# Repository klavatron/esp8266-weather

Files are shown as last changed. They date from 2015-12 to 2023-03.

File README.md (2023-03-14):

# esp8266-weather
Esp8266 based weather station for narodmon.ru or other webservices

This is a rough sketch of home weather station based on esp8266-201, esp8866-12f or LoLin NodeMCU module. It gets data from sensors and sends to narodmon.ru.

## NodeMCU board
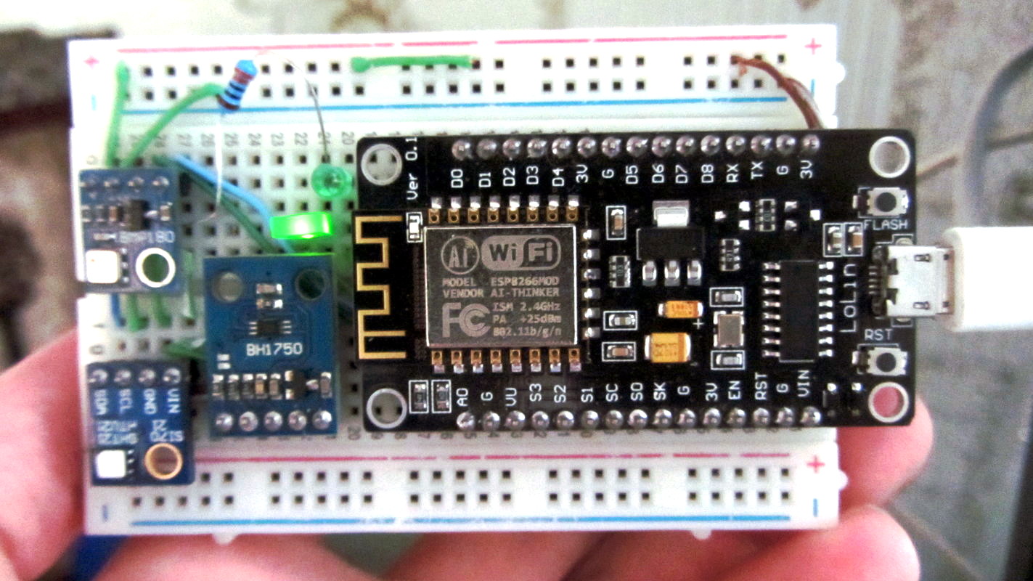
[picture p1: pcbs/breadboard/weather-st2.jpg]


### Parts used:

- Esp8266 esp-12e LoLin NodeMCU
- Breadboard
- bmp180 - barometer and thermometer
- BH1750 - Digital Light Sensor
- HTU21 - Humidity Sensor
- LED + resistor
- wires

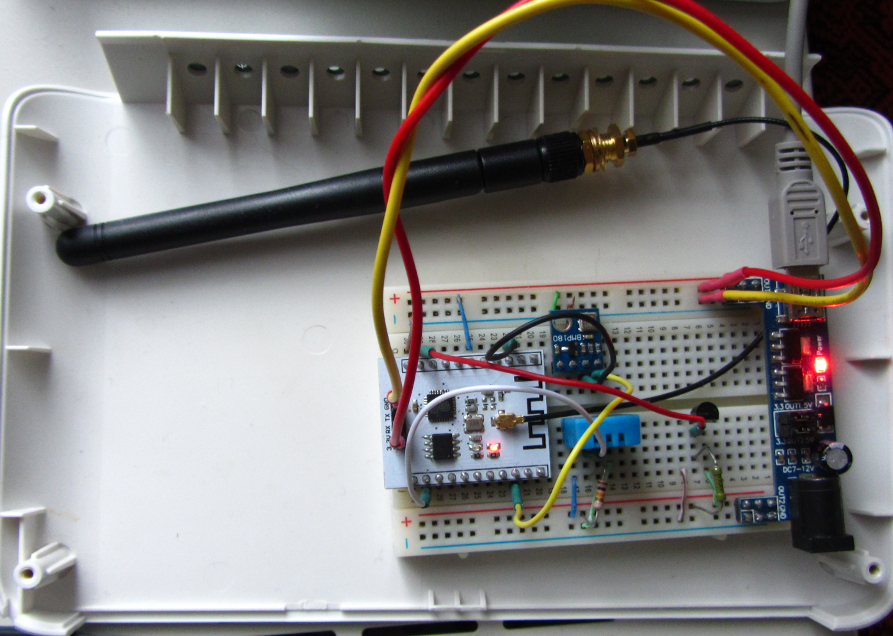
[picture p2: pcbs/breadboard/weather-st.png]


### Parts used:

- Esp8266-201 with antenna
- Breadboard
- bmp180 - barometer and thermometer
- dth11 - humidity and thermometer
- ds18b20 - termometer
- 4.7k and 10k resistors
- 3.3v power supply
- wires

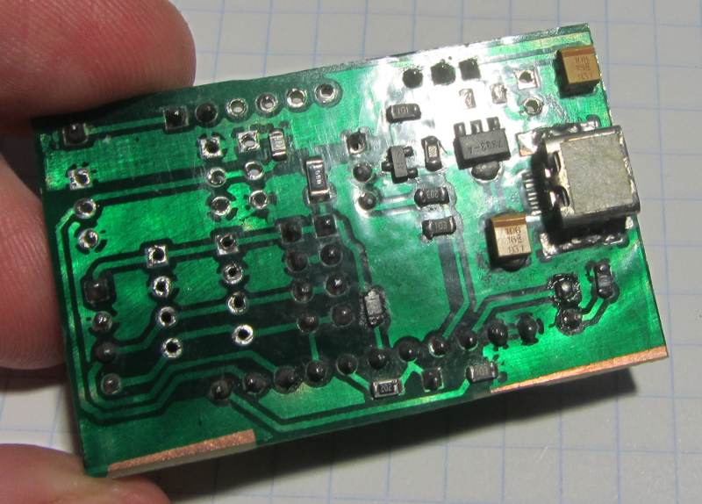
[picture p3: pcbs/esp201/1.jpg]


### Parts used:

- Esp8266-201 with antenna
- bmp180 - barometer and thermometer
- BH1750 - Digital Light Sensor
- HTU21 - Humidity Sensor
- ds18b20 - termometers
- Capacitive soil moisture sensor
- 7333 LDO 3.3v
- resistors, capacitors

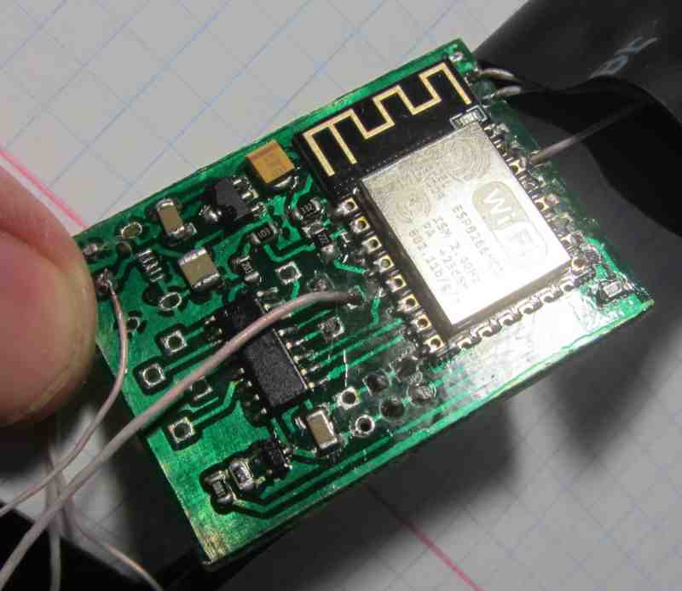
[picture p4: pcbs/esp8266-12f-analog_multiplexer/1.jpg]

  Plants monitor
### Parts used:

- Esp8266-12F
- 7 Capacitive soil moisture sensors
- 7333 LDO 3.3v
- dth11 - humidity and thermometer
- resistors, capacitors

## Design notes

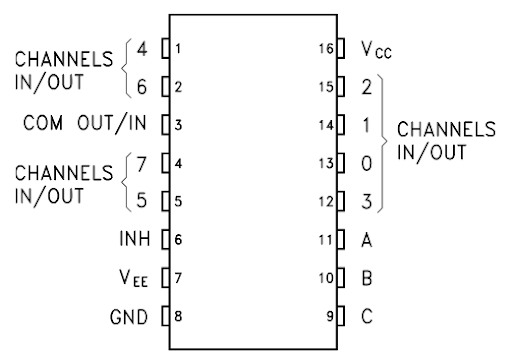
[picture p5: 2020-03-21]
img/hc4051.png

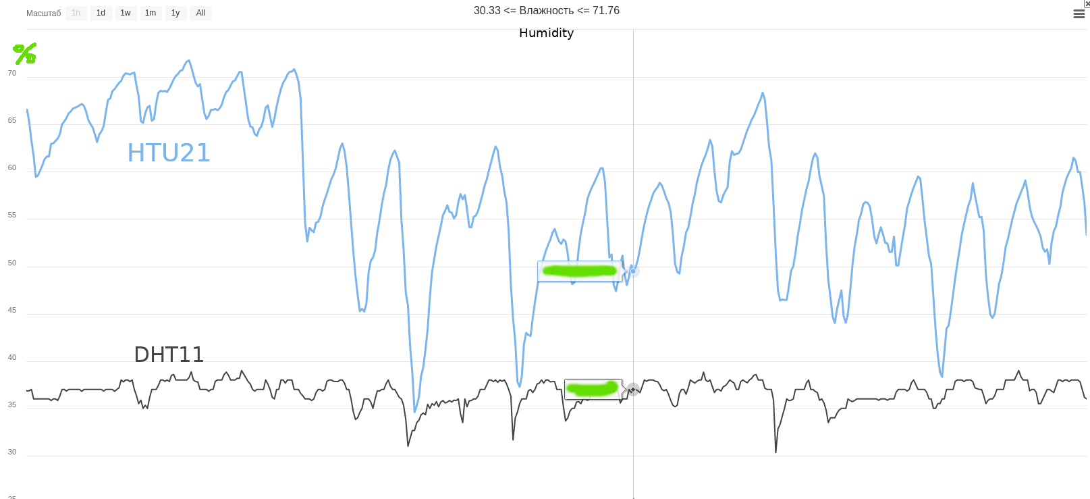
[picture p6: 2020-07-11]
img/HTU21_vs_DHT11.png

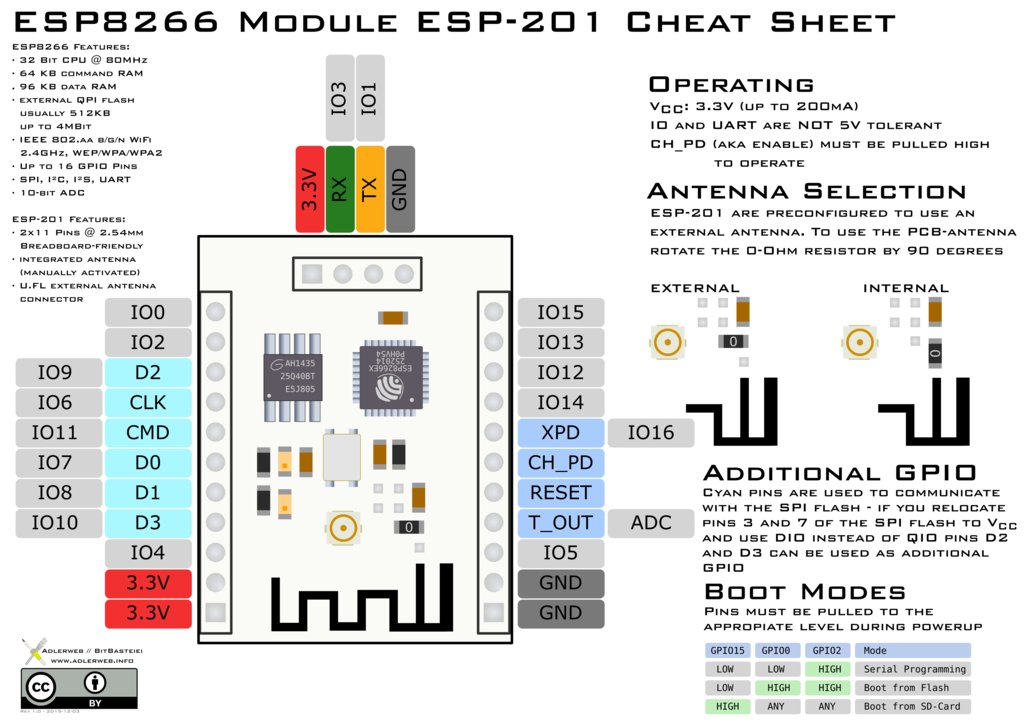
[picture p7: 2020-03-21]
img/esp201.jpg

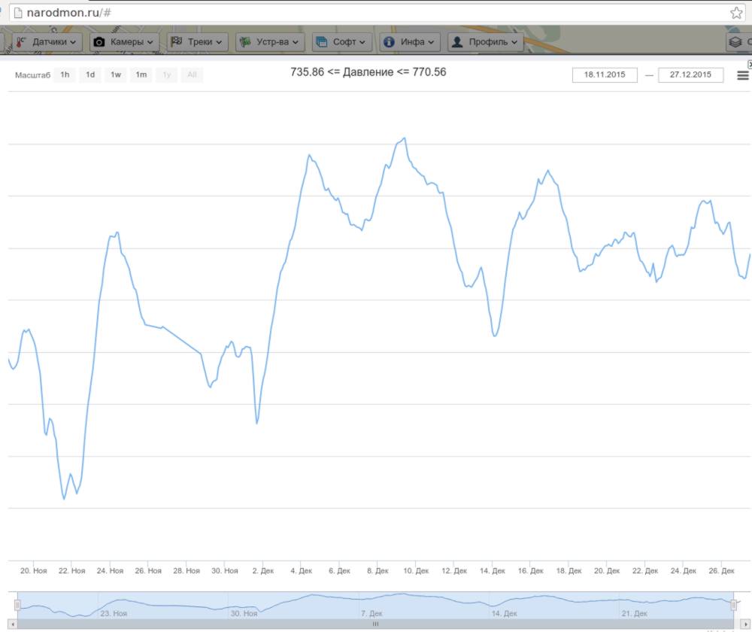
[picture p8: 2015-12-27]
img/narodmon.jpg

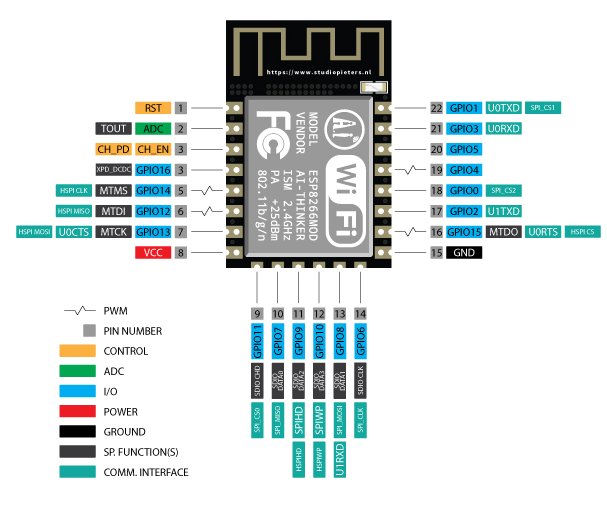
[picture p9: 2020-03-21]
img/ESP8266_12X.jpg

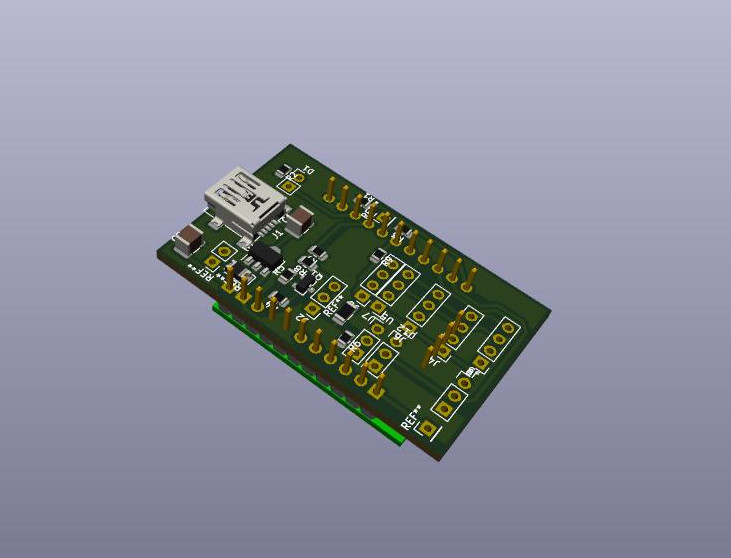
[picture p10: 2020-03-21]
pcbs/esp201/weather1.jpg

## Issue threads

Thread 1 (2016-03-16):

subzero temperature bug

klavatron, 2016-03-16:
subzero values looks like this **=-1.-19**

Closed 2016-03-23.

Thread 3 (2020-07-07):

Прошу добавить SHT1x

TerAnYu, 2020-07-07:
Здравствуйте!
Прошу добавить сенсоры SHT1x.

Библиотека: [SHT1x-ESP](https://github.com/beegee-tokyo/SHT1x-ESP)

689b6985d173bbcf6f26baad8ae21afa4a852181 - мой коммит с изменениями.
Правда есть проблема, не знаю как исправить:
при использовании BMP180 и SHT11, то BMP180 отображает какие-то странные данные, хотя при первом запросе всё корректно
```
runOnce:            Going to check sensors
readSensors:        Going to collect data
readSensors:        BMP180
bmp180 pressure     982.33 hPa
bmp180 temperature  29.70 C
SHT_T:              28.5900001526 C
SHT_H:              61.06 %
runOnce:            Sensors checked

```
далее
```
-->start
WIFI status code: 3
readSensors:        Going to collect data
readSensors:        BMP180
bmp180 pressure     2212.31 hPa
bmp180 temperature  213.00 C
SHT_T:              28.6000003815 C
SHT_H:              60.56 %
-->end
```

klavatron, 2020-07-09:
Хорошо, позже гляну.

klavatron, 2020-07-10:
Возможно, ошибка вызвана тем, что SHTxx это не i2c сенсоры. Есть ли возможность проверить работоспособность с другим i2c сенсором (не bmp180)? Работает ли SHTxx на пинах, отличных от i2c? Если да, то возникает ли описанная проблема, при одновременном подключении bmp180 к пинам с поддержкой i2c, а SHTxx к иным пинам?

TerAnYu, 2020-07-11:
С другим датчиком проверить не смог, есть только DS1631.
Перевёл SHTxx на другие пины - D2 и D3 - всё заработало как положено.
Пробовал с отключенным (но на тех же пинах) SHT11 и подключенным BMP180 - проблема сохраняется.

klavatron, 2020-07-11:
sht.begin() выдаёт ошибку, потому как такой функции, в используемой Вами [библиотеке](https://github.com/beegee-tokyo/SHT1x-ESP/blob/master/SHT1x-ESP.h), нет. В своих примерах, _beegee-tokyo_ сразу опрашивает сенсор.
P.S.
dht и sht - разные сенсоры. SHTxx - 4 контакта, 2-wire serial interface; DHTxx - 3 контакта, one-wire.

**D**HT11 сенсор плохой. Хоть он и реагирует на скачки влажности, но довольно грубый и показания всегда занижены. Использовать крайне не рекомендуется. [Вот пример](https://github.com/klavatron/esp8266-weather/blob/master/img/HTU21_vs_DHT11.png) показывающий разницу в измерениях между HTU21 и DHT11.

TerAnYu, 2020-07-12:
Спасибо за консультацию.

P.S.
Я свои датчики брал уще в 2012 году, выбирал только цифровые, где были низкие показатели погрешности.

klavatron, 2020-07-12:
Перекидал коммиты в [ветку](https://github.com/klavatron/esp8266-weather/tree/feature-sht). Сделал некоторые правки. Если есть возможность проверить работоспособность - будет не плохо. Если будет работать, можно слить в мастер. Не могли бы скинуть скриншот графика SHT-сенсора. Интересно посмотреть диапазоны, в которых он выдаёт показания.

TerAnYu, 2020-07-12:
Работоспособность подтверждаю.
Графики будут завтра, примерно в это же время.

TerAnYu, 2020-07-13:
Данные CSV, что бы наглядно посмотреть, местами есть вспелски.

```
UNIXTIME;DATE;TIME;01;03;BA;BB
1594475220;11.07.2020;20:47:00;987.72;28.4;47.64;28.71
1594475520;11.07.2020;20:52:00;987.64;;46.72;28.66
1594476360;11.07.2020;21:06:00;987.7;;47.7;28.45
1594564200;12.07.2020;21:30:00;985.19;;39.72;31.16
1594564800;12.07.2020;21:40:00;985.26;;39.81;31.11
1594565400;12.07.2020;21:50:00;985.31;;39.68;31.11
1594566000;12.07.2020;22:00:00;985.37;;39.01;31.14
1594566600;12.07.2020;22:10:00;985.24;;38.67;31.08
1594567260;12.07.2020;22:21:00;985.25;;39.21;31.1
1594567860;12.07.2020;22:31:00;985.17;;39.31;31.08
1594568460;12.07.2020;22:41:00;985.34;;40.07;31.04
1594569120;12.07.2020;22:52:00;985.29;29.1;40.8;30.97
1594569720;12.07.2020;23:02:00;985.45;29.4;41.89;30.9
1594570320;12.07.2020;23:12:00;985.28;29;42.2;30.96
1594570920;12.07.2020;23:22:00;985.34;29;42.24;31.09
1594571520;12.07.2020;23:32:00;985.61;29;43.34;31.12
1594572120;12.07.2020;23:42:00;986.21;29.2;43.87;31.15
1594572720;12.07.2020;23:52:00;986.5;29.1;44.53;31.16
1594573320;13.07.2020;00:02:00;986.57;29.3;45.16;31.13
1594573920;13.07.2020;00:12:00;986.71;29.2;44.92;31.12
1594574520;13.07.2020;00:22:00;986.86;29.2;44.99;31.12
1594575120;13.07.2020;00:32:00;986.62;28.9;44.81;31.02
1594575780;13.07.2020;00:43:00;986.5;28.7;45.62;30.9
1594576380;13.07.2020;00:53:00;986.65;27.7;45.71;30.57
1594576980;13.07.2020;01:03:00;986.56;27.9;46.17;30.54
1594577580;13.07.2020;01:13:00;986.51;28.2;46.08;30.33
1594578180;13.07.2020;01:23:00;986.14;28.3;47.14;29.93
1594578780;13.07.2020;01:33:00;986.05;28.4;48.83;29.65
1594579380;13.07.2020;01:43:00;986.37;27.6;49.05;29.36
1594580040;13.07.2020;01:54:00;986.23;27.1;49.48;28.93
1594580640;13.07.2020;02:04:00;986.44;28.1;50.06;28.7
1594581240;13.07.2020;02:14:00;986.46;28.2;50.47;28.6
1594581840;13.07.2020;02:24:00;986.3;28.3;50.9;28.51
1594582440;13.07.2020;02:34:00;986.21;28.3;51.38;28.42
1594583040;13.07.2020;02:44:00;985.98;28.3;52.77;28.35
1594583640;13.07.2020;02:54:00;985.91;27.6;52.12;28.25
1594584240;13.07.2020;03:04:00;985.66;25.9;50.57;27.95
1594584840;13.07.2020;03:14:00;985.43;25.9;50.54;27.72
1594585500;13.07.2020;03:25:00;985.29;25.4;50.87;27.51
1594586100;13.07.2020;03:35:00;985.82;26.2;51.46;27.41
1594586700;13.07.2020;03:45:00;986.01;26.7;51.95;27.48
1594587300;13.07.2020;03:55:00;985.94;26;52.17;27.42
1594587900;13.07.2020;04:05:00;986.15;26.1;52.51;27.35
1594588500;13.07.2020;04:15:00;986.36;27.1;52.32;27.4
1594589100;13.07.2020;04:25:00;986.47;27.3;53.06;27.46
1594589760;13.07.2020;04:36:00;986.48;26.8;53.83;27.48
1594590360;13.07.2020;04:46:00;986.56;27.3;52.62;27.48
1594590960;13.07.2020;04:56:00;986.41;27.4;52.4;27.48
1594591560;13.07.2020;05:06:00;986.56;27.4;52.43;27.49
1594592160;13.07.2020;05:16:00;986.49;27.5;52.15;27.53
1594592760;13.07.2020;05:26:00;986.37;27.4;51.95;27.53
1594593360;13.07.2020;05:36:00;986.38;27.4;51.93;27.53
1594593960;13.07.2020;05:46:00;986.39;27.4;52.59;27.54
1594594620;13.07.2020;05:57:00;986.5;27.5;52.44;27.54
1594595220;13.07.2020;06:07:00;986.34;27.4;52.53;27.53
1594595880;13.07.2020;06:18:00;986.46;27.4;53.42;27.51
1594596480;13.07.2020;06:28:00;986.4;27.3;52.62;27.48
1594597080;13.07.2020;06:38:00;986.49;27.3;52.2;27.46
1594597680;13.07.2020;06:48:00;986.57;27.3;52.24;27.47
1594598280;13.07.2020;06:58:00;986.55;27.3;52.55;27.46
1594598880;13.07.2020;07:08:00;986.5;27.2;52.49;27.46
1594599480;13.07.2020;07:18:00;986.56;27.2;52.74;27.44
1594600080;13.07.2020;07:28:00;986.63;27.2;52.71;27.4
1594600680;13.07.2020;07:38:00;986.69;27.1;53.31;27.39
1594601280;13.07.2020;07:48:00;986.82;27.1;53.08;27.35
1594601880;13.07.2020;07:58:00;987;27.1;53.2;27.31
1594602480;13.07.2020;08:08:00;987.11;27.2;53.42;27.3
1594603080;13.07.2020;08:18:00;987.08;27.1;53.29;27.29
1594603740;13.07.2020;08:29:00;987.16;27.2;53.73;27.26
1594604340;13.07.2020;08:39:00;987.14;27.1;53.6;27.26
1594604940;13.07.2020;08:49:00;987.13;27.1;53.57;27.26
1594605540;13.07.2020;08:59:00;987.12;27.1;53.41;27.24
1594606140;13.07.2020;09:09:00;987.08;27;53.28;27.23
1594606740;13.07.2020;09:19:00;987.13;27.1;53.22;27.25
1594607340;13.07.2020;09:29:00;987.05;27.1;53.12;27.22
1594607940;13.07.2020;09:39:00;987.2;27.1;53.09;27.24
1594608600;13.07.2020;09:50:00;987.18;27.2;53.09;27.24
1594609200;13.07.2020;10:00:00;987.29;27.1;53.15;27.21
1594609800;13.07.2020;10:10:00;987.41;27.1;53.03;27.21
1594610400;13.07.2020;10:20:00;987.47;27.1;52.96;27.18
1594611000;13.07.2020;10:30:00;987.71;27.1;52.77;27.16
1594611600;13.07.2020;10:40:00;987.81;27.1;52.73;27.15
1594612200;13.07.2020;10:50:00;987.92;27;52.7;27.14
1594612800;13.07.2020;11:00:00;987.92;27;52.51;27.14
1594613400;13.07.2020;11:10:00;988;27.1;52.64;27.15
1594614060;13.07.2020;11:21:00;988;27.2;52.58;27.17
1594614660;13.07.2020;11:31:00;988.05;27.1;52.58;27.18
1594615260;13.07.2020;11:41:00;988.13;27.2;52.49;27.2
1594615860;13.07.2020;11:51:00;988.1;27.2;52.52;27.2
1594616460;13.07.2020;12:01:00;988.02;27.3;52.46;27.22
1594617060;13.07.2020;12:11:00;988;27.3;52.46;27.25
1594617600;13.07.2020;12:20:00;988.1;27.4;52.91;27.28
1594618260;13.07.2020;12:31:00;988.19;27.4;52.63;27.32
1594618800;13.07.2020;12:40:00;988.12;27.4;52.34;27.32
1594619460;13.07.2020;12:51:00;988.09;27.4;52.57;27.32
1594620060;13.07.2020;13:01:00;988.12;27.4;53.05;27.34
1594620600;13.07.2020;13:10:00;988.29;27.4;53.4;27.35
1594621260;13.07.2020;13:21:00;988.24;27.4;53.75;27.34
1594621860;13.07.2020;13:31:00;988.17;27.4;54.47;27.34
1594622460;13.07.2020;13:41:00;988.16;27.4;55.92;27.34
1594623060;13.07.2020;13:51:00;988.15;27.5;57.59;27.38
1594623660;13.07.2020;14:01:00;988.15;27.6;58.54;27.43
1594624260;13.07.2020;14:11:00;988.03;27.7;58.17;27.48
1594624860;13.07.2020;14:21:00;988.07;27.7;57.83;27.49
1594625520;13.07.2020;14:32:00;988.17;27.7;57.61;27.51
1594626120;13.07.2020;14:42:00;988.11;27.6;56.77;27.53
1594626720;13.07.2020;14:52:00;988.05;27.7;56.49;27.53
1594627320;13.07.2020;15:02:00;988;27.7;56.11;27.56
1594627920;13.07.2020;15:12:00;988.08;27.7;55.55;27.59
1594628520;13.07.2020;15:22:00;988.07;27.7;54.67;27.6
1594629120;13.07.2020;15:32:00;988.1;27.7;54.8;27.61
1594629720;13.07.2020;15:42:00;988.14;27.8;55.62;27.62
1594630320;13.07.2020;15:52:00;988.2;27.8;55.72;27.63
1594630920;13.07.2020;16:02:00;988.27;27.8;55.81;27.67
1594631520;13.07.2020;16:12:00;988.38;27.8;55.78;27.66

```

klavatron, 2020-07-13:
В первых строках лога у bmp180 отсутствует показания температуры? Странно. Когда зависла, вывод серийного порта куда-то писался? Собрано на макетке или запаяно? Спящий режим не используется? Питание не проседает на датчиках? У меня раньше были проблемы с каким-то датчиком, он наглухо вешался. По этой причине стал запитывать сенсоры через мосфет, включаемый на время опроса сенсоров. Стало работать стабильнее.

TerAnYu, 2020-07-14:
bmp180 я позже включил, решил для сравнения добавить. К сожалению вывод никуда не писался.
Сегодня опять завис.
Датчики припаяны, правда на проводах...
Спящий режим вроде не используется.
Завтра попробую на WeMos переделать.
Питание через блок питания с литиевым аккумулятором, якобы бесперебойник. Питание не проверял, думаю что 1А должно хватать :)
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

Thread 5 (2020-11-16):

Звисание устройства

TerAnYu, 2020-11-16:
Здравствуйте!
Получилось, наконец-таки, собрать дамп, когда данные перестают передаваться:
```
-->start
WIFI status code: 3
readSensors:        Going to collect data
readSensors:        BMP180
bmp180 pressure     1000.42 hPa
bmp180 temperature  27.00 C
SHT_T:              30.0400009155 C
SHT_H:              32.84 %

Compiled string: ID=MACADDRESSS000000&MACADDRESSS00000001=1000.42&MACADDRESSS00000003=27.00&MACADDRESSS000000BA=32.84&MACADDRESSS000000BB=30.04
=============== send msg start ==============
-------------- host unreachable -------------
reboot in 10 sec
---------------------------------------------

```
После этого устройство более не отвечает, пока не перезапустишь по питанию.

klavatron, 2020-11-16:
Приветствую! RST через резистор (например 3Ком) подключен на GPIO16?

TerAnYu, 2020-11-16:
Спасибо!
Был не в курсе такого нюанса и в документации тоже не написано.
В моём случае помогла только перемычка (между RST и D0).

klavatron, 2020-11-16:
Надо добавить в описание этот нюанс. Дело в том, что при использовании "спящего режима", а он там использовался, чтобы ESP8862 нормально проснулась, надо ногу RST подключать к WAKE (GPIO16 она же D0). Вместо перемычки, всё же лучше подобрать резистор.

Closed 2020-11-16.

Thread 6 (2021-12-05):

Отрицательные температуры отображаются коряво ds18b20

b8hri11, 2021-12-05:
Отрицательные температуры отображаются коряво
2021-12-05 10:06:29  *.*.*.*  POST  28FF2D94A2150478=--2.0-94 not a number  ID=*&28FF2D94A2150478=--2.0-94

klavatron, 2021-12-06:
хм... действительно

klavatron, 2021-12-06:
Поправил

Closed 2021-12-06.

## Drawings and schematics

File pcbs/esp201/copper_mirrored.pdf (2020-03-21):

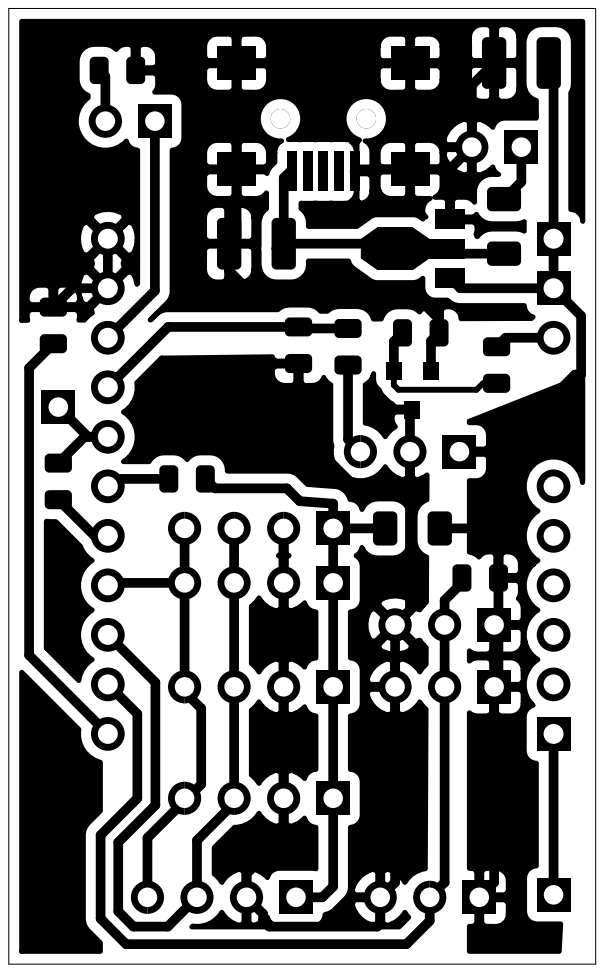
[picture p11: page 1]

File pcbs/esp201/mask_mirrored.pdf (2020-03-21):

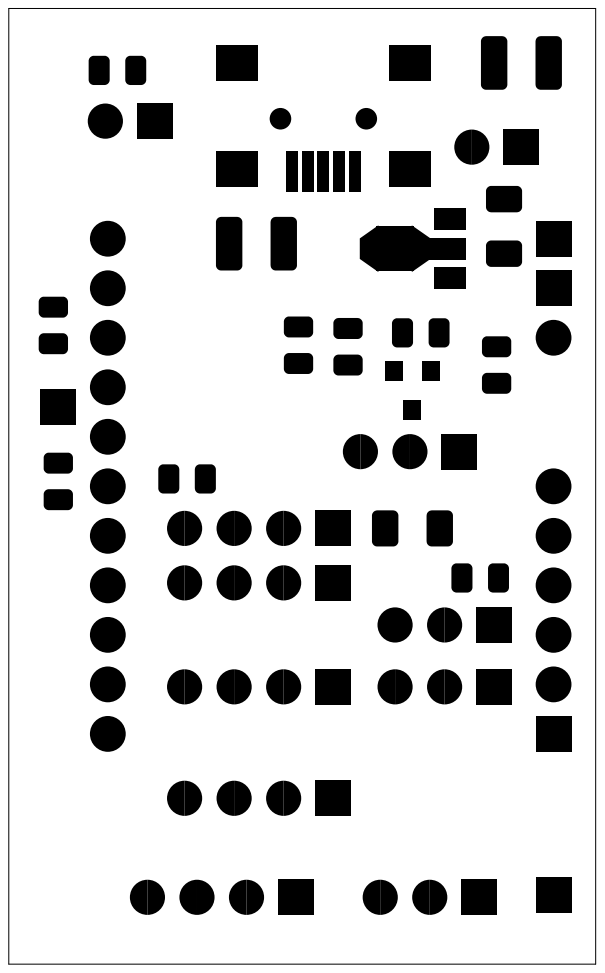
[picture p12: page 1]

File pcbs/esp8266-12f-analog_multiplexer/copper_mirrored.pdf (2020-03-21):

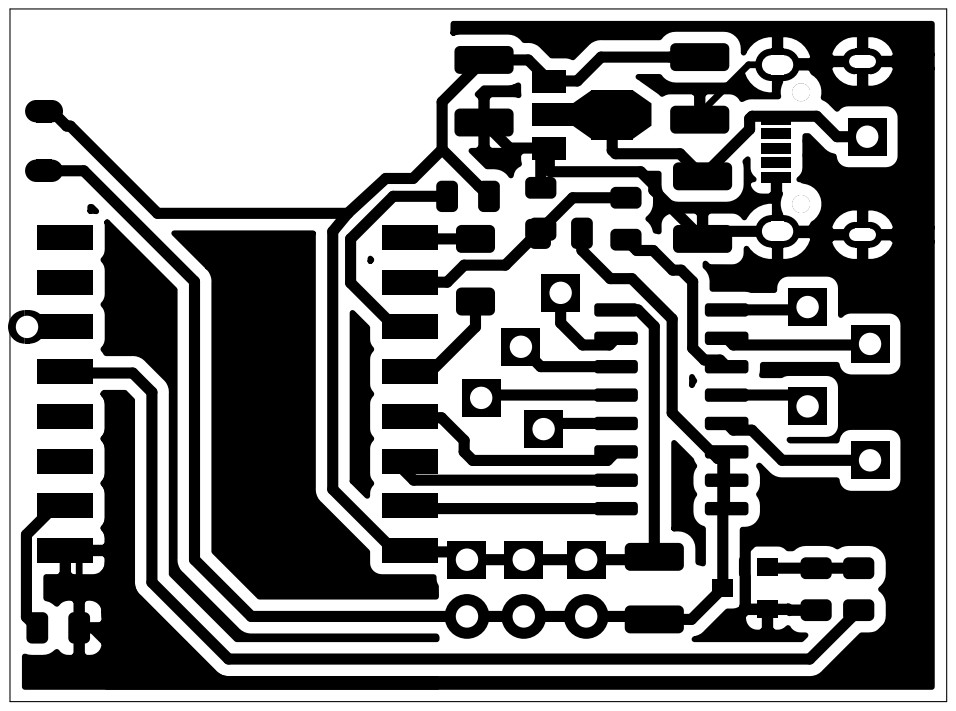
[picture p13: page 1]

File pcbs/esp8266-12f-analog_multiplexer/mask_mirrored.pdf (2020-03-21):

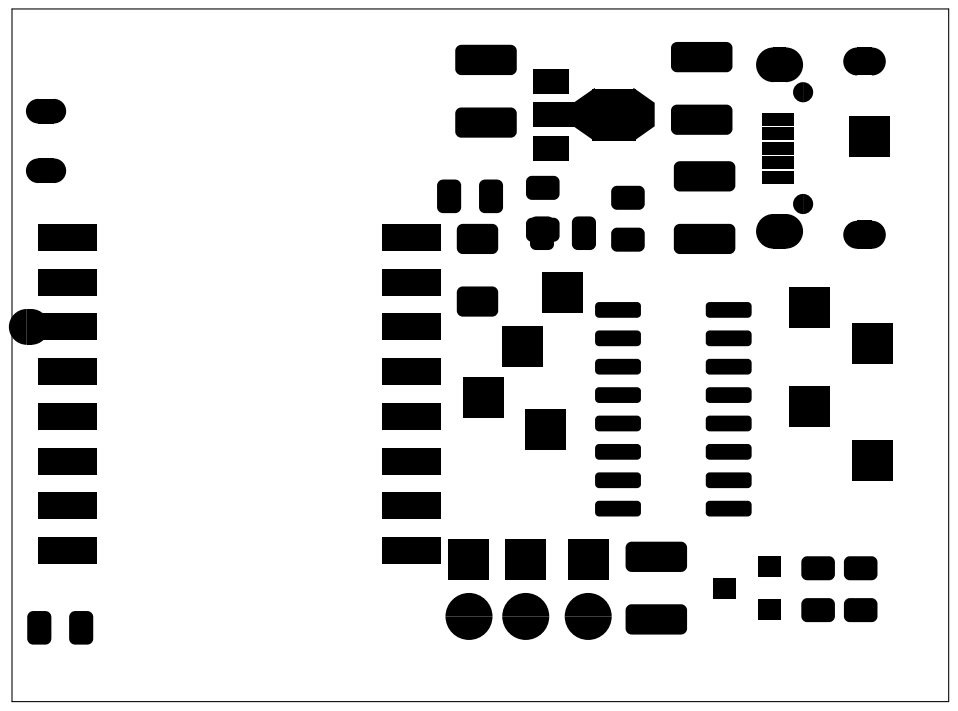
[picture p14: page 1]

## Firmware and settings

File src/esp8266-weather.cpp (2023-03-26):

/*
*  This sketch sends data via HTTP POST requests to narodmon.ru service.
*  Copyright <klavatron> 2015-2023
*
*  ***DRAFT***
*           ESP8266 BoardVersion 2.6.3 https://github.com/esp8266/Arduino
*
*  List of supported sensors:
*                         Adafruit Unified Sensor Driver 1.1.4 https://github.com/adafruit/Adafruit_Sensor
*           bmp180  i2c   Adafruit BMP085 Unified 1.1.0 https://github.com/adafruit/Adafruit_BMP085_Unified
*                         Adafruit GFX Library 1.1.8 https://github.com/adafruit/Adafruit-GFX-Library
*           OLED    i2c   2.0.1 Adafruit SSD1306 oled driver library for monochrome 128x64 and 128x32 
*                               displays https://github.com/adafruit/Adafruit_SSD1306
*           BH1750  i2c   1.1.4 Christopher Laws https://github.com/claws/BH1750.git
*           !HTU21  i2c   1.0.2 Adafruit HTU21DF Library with modified begin() 
*             -->               function https://github.com/klavatron/Adafruit_HTU21DF_Library.git
*           *(dont use it) CCS811  i2c   1.0.1 DFRobot_CCS811 https://github.com/DFRobot/DFRobot_CCS811
*           dth11         Adafruit DHT sensor library 1.3.8 https://github.com/adafruit/DHT-sensor-library
*           SHT1x   2wire       beegee-tokyo  https://github.com/beegee-tokyo/SHT1x-ESP
*           ds18b20 onewire DallasTemperature 3.7.6 https://github.com/milesburton/Arduino-Temperature-Control-Library.git
*           *Analog        You need to use voltage divider to keep analog voltage in range 0..1v (LoLin NodeMCU already has it)
*           *Multiplexer   8-ch analog Multiplexer hc4051. You need to use voltage divider to keep analog 
*                               voltage in range 0..1v (LoLin NodeMCU already has it). May be usefull for polling 7-8 Capacitive
*                               Soil Moisture sensors from one ESP device
*                           
*           Remove .example extention for wifi.cfg.h.example file
*           edit:
*             ssid = "YOUR-WIFI" - name of existing wifi AP
*             password = "YOUR-PASSWORD" - password of wifi AP
*
*           If you want to send data to narodmon.ru remove .example extention for narodmon.cfg.h.example file
*           edit:
*             narodmonDevId = "ABCDEF012345"- hw address of device
*             host = "185.245.187.136" - ip of narodmon.ru
*
*           Edit defines.h to chose your sensors. Edit pins.h to assign chosen sensord to pins of ESP8266.
*           You can't use all sensors in one device because there is not enough available pins for them.
*
* If you don't use oled screen or debug logging, switch USE_SLEEP_MODE to 1 for powersaving.
*/
#include "Arduino.h"
#include "defines.h"

void setup()
{
  #if DEBUG == 1
    Serial.begin(SERIAL_SPEED);
    Serial.print("\r\n\nSketch: ");
    Serial.println(__FILE__);
    Serial.println("Compiled: " __DATE__ ", " __TIME__);
    Serial.println("\n=================== CONFIG ==================");
  #endif //DEBUG

  #if MOSFETSENSORS == 1 //if using mosfet for powering sensors
    pinMode(POWERPIN, OUTPUT);
    turnSensorsON();
  #endif //MOSFETSENSORS

  delay(100);

  #if MUX_EXIST == 1
    #if DEBUG == 1
      Serial.println("Multiplexer         init");
    #endif //DEBUG

    pinMode(mux_data_line, INPUT);

    for (int i = 0; i < 3; i++)
    {
      pinMode(mux_control_pins[i], OUTPUT);
    }
  #endif // MUX_EXIST

  #if WEBCONFIG == 1
    // check if webconfig button pressed
    #if MUX_EXIST == 1
      muxSwitchTo(MUX_BUTTON_PIN);
      if (analogRead(A0) > 300)
      {
        isConfigMode = true;
      }
    #else // MUX_EXIST
      pinMode(BUTTON_PIN, INPUT_PULLUP);
      if (!digitalRead(BUTTON_PIN))
      {
        isConfigMode = true;
      }
    #endif // MUX_EXIST
    // ENDOF check if webconfig button pressed

    if (isConfigMode) //if mux MUX_BUTTON_PIN is high -> configboot
    {
      #if DEBUG == 1
        Serial.println("Entering configuration mode");                                                                        
      #endif // DEBUG

      WiFi.mode(WIFI_STA);
      WiFi.begin(ssid, password);

      // Wait for connection
      while ((WiFi.status() != WL_CONNECTED) && sta_connection_attempts)
      {
        delay(1000);

        #if DEBUG == 1
          Serial.print(".");
        #endif // DEBUG

        sta_connection_attempts--;
      }

      //if cant connect in STA mode, create AP
      if (sta_connection_attempts <= 0)
      {
        #if DEBUG == 1
          Serial.println("AP mode");
        #endif //DEBUG

        WiFi.mode(WIFI_AP);
        WiFi.softAP(ap_ssid, ap_password);
        IPAddress myIP = WiFi.softAPIP();

        #if DEBUG == 1
          Serial.print("AP IP address: ");
          Serial.println(myIP);
        #endif // DEBUG
      }
      else
      {
        #if DEBUG == 1
          Serial.println("");
          Serial.print("Connected to ");
          Serial.println(ssid);
          Serial.print("IP address: ");
          Serial.println(WiFi.localIP());
        #endif // DEBUG
      }

      if (!MDNS.begin(mdnshost))
      {
        #if DEBUG == 1
          Serial.println("Error setting up MDNS responder!");
        #endif // DEBUG

        while (1)
        {
          delay(1000);
        }
      }

      #if DEBUG == 1
        Serial.println("mDNS responder started");
        Serial.println("In configuration mode");
      #endif // DEBUG

      httpUpdater.setup(&httpServer, update_path, update_username, update_password);
      httpServer.begin();

      MDNS.addService("http", "tcp", 80);

      #if DEBUG == 1
        Serial.print("WEB UPDATER on ");
        Serial.println(WiFi.localIP());
        Serial.printf("HTTPUpdateServer ready! Open http://%s.local%s in your browser and login with username '%s' and password '%s'\n", mdnshost, update_path, update_username, update_password);
      #endif // DEBUG

      while (1) // loop()
      {
        httpServer.handleClient();
        MDNS.update();
      }
    }
    delay(100);
  #endif // WEBCONFIG

  #if USE_SLEEP_MODE == 0 // if not using deep sleep
    lastUpdateMillis = millis();
  #endif // USE_SLEEP_MODE

  #if NARODMON == 1
    lastSendMillis = millis();
  #endif //NARODMON

  //if I2C used
  #if (OLED == 1) || (BMP_EXIST == 1) || (BH1750_EXIST == 1) || (HTU21_EXIST == 1) || (CCS811_EXIST == 1)
    Wire.begin(WIRESDA, WIRESCL);
    delay(100);
  #endif

  #if USELED == 1
    pinMode(INDICATORLED, OUTPUT);
    digitalWrite(INDICATORLED, LOW);
  #endif //USELED

  #if OLED == 1
    if (!display.begin(SSD1306_SWITCHCAPVCC, 0x3C))
    { // bug. always TRUE // Address 0x3D for 128x64, 0x3C for 128x32 and some 128x64 oled displays
      #if DEBUG == 1
        Serial.println("OLED initialization error");
      #endif
      oled_error = true;
    }
    else
    {
      #if DEBUG == 1
        Serial.println("OLED initialization Ok");
      #endif
    }

    if (!oled_error)
    {
      delay(300);
      display.clearDisplay();
      display.setTextSize(1);
      display.setTextColor(WHITE);
      display.setCursor(0, 0);
      display.println("ESP weather");
      display.display();
      delay(500);
    }
  #endif //OLED

  #if WIFI == 1
    #if OLED == 1
      if (!oled_error)
      {
        display.clearDisplay();
        display.setCursor(0, 0);
        display.println("Connecting to: ");
        display.setCursor(0, 16);
        display.println(ssid);
        display.display();
      }
    #endif //OLED

    #if DEBUG == 1
      #if NARODMON == 1
        Serial.print("Narodmon IP:        ");
        Serial.println(host);
      #endif //NARODMON

      Serial.print("Connecting to:      ");
      Serial.print(ssid);
      Serial.print(" ");
    #endif //DEBUG

    //WiFi.forceSleepWake();
    WiFi.mode(WIFI_STA);
    delay(100);

    #if OLED == 1
      if (!oled_error)
      {
        display.setCursor(0, 32);
      }
    #endif //OLED

    if (WiFi.SSID())
    {
      #if DEBUG == 1
        Serial.print("x");
      #endif //DEBUG
      WiFi.begin();
    }
    else
    {
      #if DEBUG == 1
        Serial.print("X");
      #endif //DEBUG
      WiFi.begin(ssid, password);
    }
    delay(100);
    int attempts = 0;

    while (WiFi.status() != WL_CONNECTED)
    {
      attempts++;
      if (attempts == 10)
      {
        WiFi.begin(ssid, password);
      }
      if (attempts > 20)
      {
        wifi_error = true;
        break;
      }
      delay(1000);

      #if DEBUG == 1
        Serial.print(".");
      #endif //DEBUG

      #if OLED == 1
        if (!oled_error)
        {
          display.print(".");
          display.display();
        }
      #endif //OLED

      #if USELED == 1
        ledBlink(50, 1);
      #endif //USELED
    }

    #if USELED == 1
      ledBlink(100, 2);
    #endif //USELED

    #if DEBUG == 1
      if (!wifi_error)
      {
        Serial.println(" OK");
        Serial.print("IP address:         ");
        Serial.println(WiFi.localIP());
      }
      else
      {
        Serial.println("WiFi error");
      }
    #endif //DEBUG

    #if OLED == 1
      if (!oled_error)
      {
        if (!wifi_error)
        {
          delay(50);
          display.println("OK");
          display.display();
          display.setCursor(0, 48);
          display.print("IP:");
          display.println(WiFi.localIP());
          display.display();
        }
        else
        {
          delay(50);
          display.println("WiFi Err");
          display.display();
        }
      }
    #endif //OLED

    delay(500);
  #endif //WIFI

  #if DALLAS_EXIST == 1
    delay(50);
    dallas_sensors.begin();
    countOfDallasTerm = dallas_sensors.getDeviceCount();

    if (countOfDallasTerm <= 0)
      dallas_error = true;

    #if DEBUG == 1
      Serial.print("Locating dallas devices...\t");
      (countOfDallasTerm > 0) ? Serial.print(" OK\n") : Serial.print(" FAIL\n");
      Serial.print("Found ");
      Serial.print(countOfDallasTerm, DEC);
      Serial.println(" devices.");
    #endif //DEBUG

    if (!dallas_error)
    {
      for (int i = 0; i < countOfDallasTerm; i++)
      {
        // Search the wire for address
        if (dallas_sensors.getAddress(tempDeviceAddress, i))
        {
          #if DEBUG == 1
            Serial.print("Dallas thermometer: ");
            printAddress(tempDeviceAddress);
            Serial.println();
          #endif //DEBUG
          // set the resolution to 9 bit (Each Dallas/Maxim device is capable of several different resolutions)
          dallas_sensors.setResolution(tempDeviceAddress, TEMPERATURE_PRECISION);
        }
        else
        {
          #if DEBUG == 1
            Serial.print("Found ghost device at ");
            Serial.print(i, DEC);
            Serial.print(" but could not detect address. Check power and cabling");
          #endif //DEBUG
        }
      }
    }
  #endif //DALLAS_EXIST

  #if BMP_EXIST == 1
    delay(50);
    if (!presureSensor.begin())
    {
      #if DEBUG == 1
        Serial.println("BMP                 fail");
      #endif //DEBUG
      bmp_error = true;
    }
    else
    {
      #if DEBUG == 1
        Serial.println("BMP                 init");
      #endif //DEBUG
      getBMPsensor();
    }
  #endif //BMP_EXIST

  #if BH1750_EXIST == 1
    delay(50);

    if (lightMeter.begin(BH1750::CONTINUOUS_HIGH_RES_MODE_2))
    {
      #if DEBUG == 1
        Serial.println("BH1750              init");
      #endif //DEBUG
    }
    else
    {
      bh1750_error = true;
      #if DEBUG == 1
        Serial.println("BH1750              fail");
      #endif //DEBUG
    }
  #endif //BH1750_EXIST

  #if ANALOG_SENSOR == 1
    delay(50);
    pinMode(ANALOG_PIN, INPUT);

    #if DEBUG == 1
      Serial.println("Analog pin          init");
    #endif //DEBUG

  #endif //ANALOG_SENSOR

  #if DHT_EXIST == 1
    #if DEBUG == 1
      Serial.println("DHT                 init");
    #endif //DEBUG
    dht.begin();
    delay(100);
  #endif //DHT_EXIST

  #if SHT_EXIST == 1
    #if DEBUG == 1
      Serial.println("SHT                 init");
    #endif //DEBUG
  #endif //SHT_EXIST

  #if HTU21_EXIST == 1
    delay(50);

    if (!htu21.begin())
    {
      #if DEBUG == 1
        Serial.println("Error. Couldn't find HTU21!");
      #endif //DEBUG
      htu21_error = true;
    }
    else
    {
      #if DEBUG == 1
        Serial.println("HTU21               init");
      #endif //DEBUG
    }
  #endif //HTU21_EXIST

  #if CCS811_EXIST == 1 // <-------- i2c
    delay(50);

    if(ccs.begin() != 0){
      #if DEBUG == 1
        Serial.println("Failed to start sensor! Please check your wiring.");
      #endif //DEBUG
      ccs811_error = true;
    }
    else{
      #if DEBUG == 1
        Serial.println("CCS811              init");
      #endif //DEBUG
    }
  #endif //CCS811_EXIST


  #if DEBUG == 1
    Serial.println("=============== END OF CONFIG ===============");
    Serial.println("");
  #endif
  delay(100);

  runOnce();
} // setup()

void loop()
{
  #if USE_SLEEP_MODE != 1
    currentUpdateMillis = millis();
    if (currentUpdateMillis - lastUpdateMillis >= updateInterval)
    {
      lastUpdateMillis = currentUpdateMillis;
      update_flag = true;
    }

    // if it's time to update - read sensors, send data
    if (update_flag == true)
    {
      #if DEBUG == 1
        Serial.println("\r\n\n-->start");
        Serial.print("WIFI status code: ");
        Serial.println(WiFi.status());
      #endif //DEBUG

      readSensors();

      #if USELED == 1
        ledBlink(200, 3);
      #endif //USELED

      #if OLED == 1
        displayDraw();
      #endif //OLED

      #if NARODMON == 1
        currentSendMillis = millis();

        if (currentSendMillis - lastSendMillis >= sendPeriod)
        {
          lastSendMillis = currentSendMillis;
          send_allow_flag = true;
        }
        else
        {
          #if DEBUG == 1
            Serial.print("Next delivery in ");
            Serial.print(round((sendPeriod - (currentSendMillis - lastSendMillis)) / 1000));
            Serial.println(" seconds");
          #endif //DEBUG
        }

        // if it's time to send post message - send message
        if (send_allow_flag == true)
        {
          if (!wifi_error)
          {
            send_message(POST_string);
          }
          else
          {
            #if DEBUG == 1
              Serial.println("Cannt POST to server. WiFi error");
            #endif
          }
        }
      #endif //narodmon

      update_flag = false;
      #if DEBUG == 1
        Serial.println("-->end");
      #endif //DEBUG
    }    //if(update_flag == true)
  #endif //!USE_SLEEP_MODE
} // loop()

String floatToString(float src, char decimal_point)
{
  String data = "";
  if (src < 0) //check for minus sign
  {
    data = "-";
  }
  int a, b, c;
  a = (int)abs(round(src * 100));
  b = (int)floor(a / 100);
  c = (int)floor(a % 100);
  data += String(b);
  data += String(decimal_point);

  if (c >= 10)
  {
    data += String(c);
  }
  else
  {
    data += "0";
    data += String(c);
  }
  return data;
} // floatToString()

#if USE_SLEEP_MODE == 1
  void goto_sleep()
  {
    #if DEBUG == 1
      Serial.println("Do nothing for 10 seconds"); // This makes it easier to re-flash the chip later.
    #endif                                         //DEBUG
      delay(10000);

    #if DEBUG == 1
      Serial.print("Going to sleep for ");
      Serial.print(round(SLEEPING_TIME / 60e6));
      Serial.println(" min");
    #endif //DEBUG

    #if MOSFETSENSORS == 1
      turnSensorsOFF();
    #endif //MOSFETSENSORS

    #if USELED == 1
      ledBlink(400, 3);
    #endif
      ESP.deepSleep(SLEEPING_TIME, WAKE_RF_DEFAULT); //20 sec

    #if DEBUG == 1
      Serial.println("Why im not sleeping?");
    #endif //DEBUG
  } // goto_sleep()
#endif //USE_SLEEP_MODE

#if USELED == 1
  void ledBlink(int duration, int count)
  {
    for (int i = 0; i < count; i++)
    {
      digitalWrite(INDICATORLED, HIGH); // turn the LED on
      delay(duration);
      digitalWrite(INDICATORLED, LOW); // turn the LED off
      delay(duration);
    }
  } // ledBlink()
#endif //USELED

#if NARODMON == 1
void send_message(String data)
{
  #if DEBUG == 1
    Serial.println("=============== send msg start ==============");
  #endif //DEBUG

  #if WIFI == 1
    if (WiFi.status() == WL_CONNECTED)
    {
      WiFiClient client;
      if (!client.connect(host, httpPort))
      {
        #if DEBUG == 1
          Serial.println("-------------- host unreachable -------------");
          Serial.println("               reboot in 10 sec              ");
          Serial.println("---------------------------------------------");
        #endif //DEBUG
        #if USELED == 1
          ledBlink(50, 5);
        #endif
          ESP.deepSleep(10000, WAKE_RF_DEFAULT); //sleep 10 sec
      }

      #if DEBUG == 1
        Serial.println("WIFI:               Connected\n");
      #endif //DEBUG

      client.print(String("POST http://narodmon.ru/post.php HTTP/1.0\r\nHost: narodmon.ru\r\nContent-Type: application/x-www-form-urlencoded\r\n"));
      client.print(String("Content-Length: " + String(data.length()) + "\r\n\r\n" + data + "\r\n\r\n"));

      #if DEBUG == 1
        Serial.println(String("POST http://narodmon.ru/post.php HTTP/1.0\r\nHost: narodmon.ru\r\nContent-Type: application/x-www-form-urlencoded\r\n"));
        Serial.println(String("Content-Length: " + String(data.length()) + "\r\n\r\n" + data + "\r\n\r\n"));
        Serial.println("Server reply begin =====>");
      #endif //DEBUG

      delay(50);
      while (client.available())
      {
        String line = client.readStringUntil('\r');

        #if DEBUG == 1
          Serial.print(line);
          Serial.print(String(line.length()));
        #endif //DEBUG

        #if OLED == 1
          if (!oled_error)
          {
            display.clearDisplay();
            display.setCursor(0, 0);
            display.println(line.substring(0, 20));
            display.display();
          }
        #endif //OLED

        delay(100);
      }
      #if DEBUG == 1
        Serial.println("Server reply end <===== ");
        Serial.println("closing connection");
      #endif //DEBUG

      client.stop();
      #if DEBUG == 1
        Serial.println("wait 3 sec...");
      #endif //DEBUG
      delay(3000);
    }
    else
    {
      #if DEBUG == 1
        Serial.println("------------- wifi not connected ------------");
        Serial.println("               reboot in 10 sec              ");
        Serial.println("---------------------------------------------");
      #endif // DEBUG
      #if USELED == 1
        ledBlink(100, 5);
      #endif
      ESP.deepSleep(10000, WAKE_RF_DEFAULT); //sleep 10 sec

      #if DEBUG == 1
        Serial.println("Why im not sleeping?");
      #endif //DEBUG
    }
  #endif //WIFI
  send_allow_flag = false;

  #if DEBUG == 1
    Serial.println("=============== send msg end ==============");
  #endif //DEBUG
} // send_message()
#endif //NARODMON
// ###########################

void runOnce()
{
  #if DEBUG == 1
    Serial.println("runOnce:            Going to check sensors");
  #endif //DEBUG

  readSensors();

  #if DEBUG == 1
    Serial.println("runOnce:            Sensors checked");
  #endif //DEBUG

  #if OLED == 1
    displayDraw();
  #endif //oled

  #if USE_SLEEP_MODE == 1
    checkResetInfo(); // send request to server if waked after sleep
  #endif // USE_SLEEP_MODE

  #if USELED == 1
    ledBlink(100, 3);
  #endif // USELED

  #if NARODMON == 1
    POST_string = "";
  #endif //NARODMON

  #if USE_SLEEP_MODE == 1
    goto_sleep();
  #endif //USE_SLEEP_MODE
} // runOnce()
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

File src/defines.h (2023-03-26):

#pragma once
#include "Arduino.h"

/*
 * #define SOME_FEATURE 0 
 * bool some_feature_error = false;
 * 
 * #if SOME_FEATURE == 1
 *    #include ...
 *    float ...
 *    ....
 * #endif //SOME_FEATURE
 */

#define DEBUG 1          // serial logging enabled
#define USELED 0         // led indicator enabled
#define USE_SLEEP_MODE 1 // powersaving sleep mode enabled
#define MOSFETSENSORS 0  // using mosfet to powering sensors
#define WIFI 1           // wifi connection enabled
#define OLED 0           // i2c oled screen enabled
#define NARODMON 1       // sending data to narodmon enabled
#define BMP_EXIST 0      // i2c bmp075 presure sensor enabled
#define BH1750_EXIST 0   // i2c bh1750 light sensor enabled
#define HTU21_EXIST 0    // i2c HTU21 humidity sensor enabled (address 0x40)
#define CCS811_EXIST 0   // (dont use it) i2c CCS811 eCO2 sensor enabled.
#define DALLAS_EXIST 0   // onewire ds18b20 sensors enabled
#define ANALOG_SENSOR 0  // Analog sensor
#define DHT_EXIST 0      // dht11 sensor enabled
#define SHT_EXIST 0      // sht1x sensor enabled
#define MUX_EXIST 0      // analog multiplexer
#define WEBCONFIG 1      // enable web configurator. In case of esp-201 it may not work

#include "pins.h"

String floatToString(float src, char decimal_point = '.'); //Transform the float value to a string with custom decimal point symbol
void readSensors();                                        //read sensors, collect data to query string
unsigned long lastUpdateMillis;                            //providing time delay between sensors data update
unsigned long currentUpdateMillis;
const unsigned long updateInterval = 30000; // 30000 = 30 sec
bool update_flag = false;                   //if ready to update
void runOnce();                             // main function for deep sleep mode

//error flags if errors detected
bool oled_error = false;
bool bmp_error = false;
bool bh1750_error = false;
bool htu21_error = false;
bool ccs811_error = false;
bool dallas_error = false;
bool dht_error = false;
bool sht_error = false;
bool wifi_error = false;

#if DEBUG == 1
  const uint32_t SERIAL_SPEED=115200;
#endif //DEBUG

//if using pin to powering sensors
#if MOSFETSENSORS == 1
  void turnSensorsON();
  void turnSensorsOFF();
#endif //MOSFETSENSORS

#if USE_SLEEP_MODE == 1
  #define SLEEPING_TIME 600e6 // 20 sec 20e6; 600e6 - 10 min
  void checkResetInfo();
#endif //USE_SLEEP_MODE

//if using pin for led indicator
#if USELED == 1
  void ledBlink(int, int); // blink led (duration, count)
#endif //USELED

#if NARODMON == 1
  #include "narodmon.cfg.h"
  String POST_string = "";      //query string
  bool send_allow_flag = false; // allow http request
  unsigned long lastSendMillis;
  unsigned long currentSendMillis;
#endif //NARODMON

#if WIFI == 1
  #include <ESP8266WiFi.h>
  #include "wifi.cfg.h"
  #if WEBCONFIG == 1
    #include <WiFiClient.h>
    #include <ESP8266WebServer.h>
    #include <ESP8266mDNS.h>
    #include <ESP8266HTTPUpdateServer.h>

    bool isConfigMode = false;
    ESP8266WebServer httpServer(80);
    ESP8266HTTPUpdateServer httpUpdater;
  #endif //WEBCONFIG
#endif //WIFI

#if DALLAS_EXIST == 1
  #include <OneWire.h>
  #include <DallasTemperature.h>
  #define TEMPERATURE_PRECISION 12

  OneWire oneWire(ONE_WIRE_BUS);
  DallasTemperature dallas_sensors(&oneWire);

  int countOfDallasTerm = 0; //number of detected 18b20 thermometers
  DeviceAddress tempDeviceAddress;
  void printAddress(DeviceAddress);
  String aGetTempAddress(DeviceAddress);
  String aGetTemperature(DeviceAddress);
#endif //DALLAS_EXIST

#if BMP_EXIST == 1 // <-------- i2c
  #include <Wire.h>
  #include <Adafruit_Sensor.h>
  #include <Adafruit_BMP085_U.h>
  Adafruit_BMP085_Unified presureSensor = Adafruit_BMP085_Unified(10085);
  sensors_event_t event;
  void getBMPsensor();
#endif //BMP_EXIST

#if BH1750_EXIST == 1 // <-------- i2c
  #include <Wire.h>
  #include <BH1750.h>
  BH1750 lightMeter(0x23);
  float lux;
#endif //BH1750_EXIST

#if DHT_EXIST == 1
  #include <Adafruit_Sensor.h>
  #include <DHT.h>
  #define DHTTYPE DHT11
  //#define DHTTYPE    DHT22     // DHT 22 (AM2302)
  //#define DHTTYPE    DHT21     // DHT 21 (AM2301)
  DHT dht(DHT_SENSOR_PIN, DHTTYPE);
  float dht_t = 0.0;
  float dht_h = 0.0;
#endif //DHT_EXIST

#if SHT_EXIST == 1
  #include <SHT1x-ESP.h>
  SHT1x sht(SHT_SDA, SHT_SCL, SHT1x::Voltage::DC_3_3v);
  float sht_t_c = 0.0;
  float sht_t_f = 0.0;
  float sht_h = 0.0;
#endif //SHT_EXIST

#if HTU21_EXIST == 1 // <-------- i2c
  #include <Wire.h>
  #include "Adafruit_HTU21DF.h"
  Adafruit_HTU21DF htu21 = Adafruit_HTU21DF();

  float htu21_h = 0.0;
  float htu21_t = 0.0;
#endif //HTU21_EXIST
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

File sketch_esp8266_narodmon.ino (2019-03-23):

/*
 *  This sketch sends data via HTTP POST requests to narodmon.ru service.
 *  Copyright <klavatron> 2015-2019
 *
 *  ***DRAFT***
 *
 *  Sensors:
 *           bmp180 i2c
 *           BH1750 i2c
 *           HTU21 i2c
 *           dth11
 *           ds18b20 onewire
 *           MQ4 (trigger)
 *
 *  You need to change:
 *                      String DEV_ID = "ABCDEFABCDEF"- hw address of device
 *                      const char* ssid = "SSID" - name of wifi AP
 *                      const char* password = "PASSWORD" - password of wifi AP
 *                      const char* host = "185.245.187.136" - ip of narodmon.ru
 *
 * If you don't use oled screen or debug logging, switch USE_SLEEP_MODE to 1 for powersaving.
 */


static const uint8_t INDICATORLED   = 5;  // led indicator
static const uint8_t D0   = 16;
//static const uint8_t D1   = 5;
//static const uint8_t D2   = 4;
//static const uint8_t D3   = 0;  // SDA
//static const uint8_t D4   = 2;  // SCL 
static const uint8_t D5   = 14; // SDA  <---------ESP8266--------
static const uint8_t D6   = 12; // SCL  <---------ESP8266-------- 
//static const uint8_t D7   = 13;
//static const uint8_t D8   = 15;
//static const uint8_t D9   = 3;
//static const uint8_t D10  = 1;

#define SERIAL_SPEED 115200
#define WIRESDA 14 //esp8266 sda
#define WIRESCL 12 //esp8266 scl

#define DEBUG 1   // serial logging enabled
#define WIFI 1 // wifi connection enabled
#define OLED 0    // i2c oled screen enabled
#define NARODMON 1  // sending data to narodmon enabled
#define BMP_EXIST 1  // bmp075 presure sensor enabled
#define BH1750_EXIST 1 // bh1750 light sensor enabled
#define HTU21_EXIST 1  // HTU21 humidity sensor enabled

#define DHT_EXIST 0   // dht11 sensor enabled
#if DHT_EXIST == 1
  #define DHT11_SENSOR_PIN A0; 
#endif //DHT_EXIST

#define DALLAS_EXIST 0  // ds18b20 sensors enabled
#if DALLAS_EXIST == 1
  #define ONE_WIRE_BUS D0 
#endif // DALLAS_EXIST

#define MQ4_EXIST 0 // MQ4 methan sensor enabled
#if MQ4_EXIST == 1
  int METHAN_SENSOR_PIN = 12; 
#endif //MQ4_EXIST

#define USE_SLEEP_MODE 0 // powersaving sleep mode enabled
#if USE_SLEEP_MODE == 1
  #define SLEEPING_TIME 600e6 // 20 sec 20e6; 600e6 - 10 min
  void check_reset_info();
#endif // USE_SLEEP_MODE

#define USELED 1  // led indicator enabled
#if USELED == 1
  void led_blink(int, int); // blink led (duration, count)
#endif //USELED

String float_to_sting(float); //convert float value to a proper string
void read_sensors(); //read sensors, collect data to query string
unsigned long last_update_millis;  
unsigned long current_update_millis;
const unsigned long update_interval = 30000; // 30000 = 30 sec 
bool update_flag = false;
void run_once(); // main function

#if NARODMON == 1
  const char* host     = "185.245.187.136"; // narodmon server ip
  const int httpPort   = 80; // narodmon server port
  
  String DEV_ID = "ABCDEFABCDEF"; //replace with random device identificator (mac-address)
  String POST_string = ""; //query string

  bool send_allow_flag = false; // allow http request
  unsigned long last_send_millis;  
  unsigned long current_send_millis;
  const unsigned long send_period = 600000; // 600000 = 10 min 

#endif //NARODMON

#if WIFI == 1
  #include <ESP8266WiFi.h>
  #include <ESP8266WiFiMulti.h>  
  extern "C" {
    #include <user_interface.h>
  }
  //WiFiClient client;
  ESP8266WiFiMulti WiFiMulti;
  // Replace with your network credentials
  const char* ssid     = "SSID"; // WLAN ssid
  const char* password = "PASSWORD"; // WLAN password
  
#endif //WIFI

#if DALLAS_EXIST == 1
  #include <OneWire.h> 
  #include <DallasTemperature.h> 
  #define TEMPERATURE_PRECISION 12
  
  OneWire oneWire(ONE_WIRE_BUS);
  DallasTemperature dallas_sensors(&oneWire);
    
  int countOfDallasTerm; 
  DeviceAddress tempDeviceAddress; 
  
  #if DEBUG == 1
    void printAddress(DeviceAddress da)
    {
      for (uint8_t i = 0; i < 8; i++)
      {
        if (da[i] < 16) Serial.print("0");
        Serial.print(da[i], HEX);
      }
    }
  #endif //DEBUG

  String aGetTemperature(DeviceAddress da)
  {
      float tempC = dallas_sensors.getTempC(da);
      return float_to_sting(tempC);
  }
  
  String aGetTempAddress(DeviceAddress da)
  {
    String temps="&";
    for (uint8_t i = 0; i < 8; i++)
    {
      int a,b =0;
      a=(int)floor(da[i]/16);
      b=(int)floor(da[i]%16);
      a<10?temps+=(String)a:temps+=(String)(char((a-10)+'A'));
      b<10?temps+=(String)b:temps+=(String)(char((b-10)+'A'));
    }
    temps+="=";  
    return temps;
  }

#endif //DALLAS_EXIST


#if BMP_EXIST == 1 // <-------- i2c
  #include <Wire.h>
  #include <Adafruit_BMP085_U.h>
  Adafruit_BMP085_Unified presureSensor = Adafruit_BMP085_Unified(10085);
  
  void getBMPsensor(void)
  {
     sensor_t bmp085_sensor;
     presureSensor.getSensor(&bmp085_sensor);
  }
#endif //BMP_EXIST

#if BH1750_EXIST == 1 // <-------- i2c
  #include <Wire.h>
  #include <BH1750.h>
  BH1750 lightMeter;
#endif //BH1750_EXIST

#if DHT_EXIST == 1
  #include <dht.h>
  DHT dht11 = DHT();
#endif //DHT_EXIST

#if HTU21_EXIST == 1 // <-------- i2c
  #include <Wire.h>
  #include <HTU21D.h>
  HTU21D myHTU21D;
  float humidity =0.0;
  float temperature =0.0;
#endif //HTU21_EXIST

#if OLED == 1 // <-------- i2c
  #include <Wire.h>
  #include <Adafruit_GFX.h>
  #include <Adafruit_SSD1306.h>
  #define OLED_RESET LED_BUILTIN //4  <---------------------------------------
  Adafruit_SSD1306 display(OLED_RESET);
  
  #if (SSD1306_LCDHEIGHT != 64)
    #error("Height incorrect, please fix Adafruit_SSD1306.h!");
  #endif
    
  void display_draw();
#endif //OLED
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

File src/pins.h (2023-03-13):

#pragma once
// info
/*_________________________
  |NodeMCU PIN | GPIO PIN |
  |-----------------------|
  |    D0      |     16   |
  |    D1      |     5    |
  |    D2      |     4    |
  |    D3      |     0    | // SDA
  |    D4      |     2    | // SCL
  |    D5      |     14   | // SDA  <---------ESP8266--------
  |    D6      |     12   | // SCL  <---------ESP8266--------
  |    D7      |     13   |
  |    D8      |     15   |
  |    D9      |     3    |
  |    D10     |     1    |
  =========================

GPIOs 6,7,8,9,10 unusable*
*/

//if I2C used
#if (OLED == 1) || (BMP_EXIST == 1) || (BH1750_EXIST == 1) || (HTU21_EXIST == 1) || (CCS811_EXIST == 1 ) 
  #define WIRESDA 14 //esp8266 sda
  #define WIRESCL 12 //esp8266 scl
#endif

#if MOSFETSENSORS == 1
  #define POWERPIN 4 // mosfet for powering sensors
#endif

#if DHT_EXIST == 1
  #define DHT_SENSOR_PIN 5
#endif //DHT_EXIST

#if SHT_EXIST == 1
  #define SHT_SDA 0
  #define SHT_SCL 2
#endif //SHT_EXIST

#if DALLAS_EXIST == 1
  #define ONE_WIRE_BUS 13
#endif //DALLAS_EXIST

#if ANALOG_SENSOR == 1
  #define ANALOG_PIN A0
#endif //ANALOG_SENSOR

#if USELED == 1
  #define INDICATORLED 5 // led indicator
#endif //USELED

#if MUX_EXIST == 1
  const int mux_control_pins[] = {14, 12, 13}; // control pins for mux S1,S2,S3
  const int mux_data_line = A0;                //esp8266 input pin
#endif //MUX_EXIST

#if WEBCONFIG == 1
  #if MUX_EXIST == 1
    #define MUX_BUTTON_PIN 0 //multiplexed pin for button if
  #else //MUX_EXIST
    #define BUTTON_PIN 5
  #endif //MUX_EXIST
#endif //WEBCONFIG

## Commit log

2019-03-21 deep sleep
    Sleep mode. Bug fixes.
    [sketch_esp8266_narodmon.ino]
2019-03-23 Reboot if wifi connection lost
    [sketch_esp8266_narodmon.ino]
2019-03-28 dallas, i2c changes
2020-01-08 Fritzing sketch for esp8266-201
    [meteo_fritzing_sketch.fzz]
2020-03-21 button for OTA update
2020-07-11 Изменение пинов SHT
2020-07-12 fix. BMP180. Adafruit Unified Sensor Driver.
    [defines.h, esp8266-weather.ino]
2020-07-12 SHT 5v -> 3.3 v
2023-03-14 Cleanup. Kicad files.
    [meteo_fritzing_sketch.fzz]
